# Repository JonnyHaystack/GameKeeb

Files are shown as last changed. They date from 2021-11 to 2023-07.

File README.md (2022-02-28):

# GameKeeb

Keyboard to GameCube adapter powered by Raspberry Pi Pico

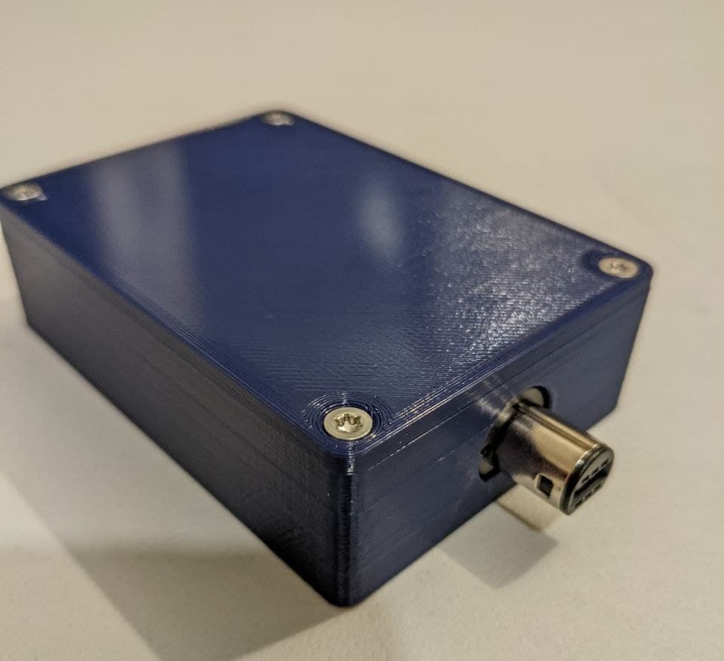
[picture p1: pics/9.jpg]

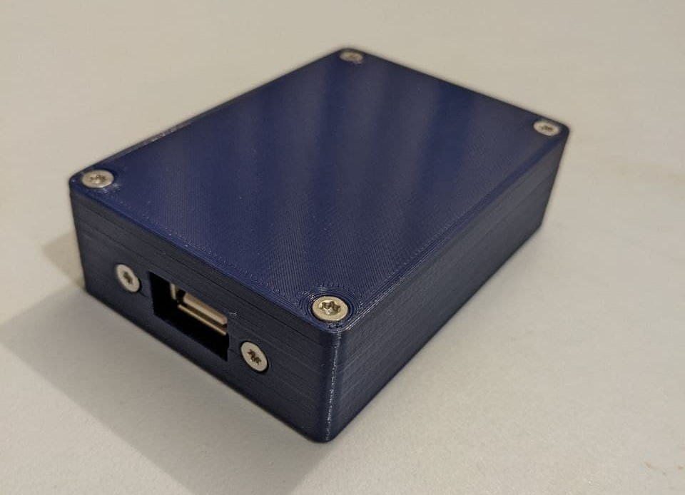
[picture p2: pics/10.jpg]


## Introduction

Someone asked me if I could make them a keyboard to GameCube adapter for
competing in Super Smash Bros Melee. I had the idea to make one using the
Raspberry Pi Pico, because it natively operates at 3.3V supply voltage and logic
level, and it has USB host support built in. Additionally, Arte had already
developed the awesome
[pico-rectangle](https://github.com/JulienBernard3383279/pico-rectangle)
firmware, so I forked it and modified it to read keycodes from a USB keyboard
instead of just GPIO inputs.

Bear in mind that USB host implementation is not as simple as it sounds, and the current
firmware is not guaranteed to work with every keyboard. In particular, it may not support all NKRO (N-Key rollover) keyboards. It should work fine with any keyboard that supports the HID boot protocol, which is very common keyboard and usually recognisable by your keyboard having 6KRO. Many NKRO keyboards will fall back to boot protocol when needed anyway. You can test your key rollover at http://gadzikowski.com/nkeyrollover.html. Support for different keyboards will be further improved in the future.

I do sell these fully assembled, so email me or [join my Discord](https://discord.com/invite/PreBbFgxxY)
if you're interested. As stated above, I cannot guarantee compatibility with
every keyboard, so I accept returns for a full refund (not including
shipping costs).

## Parts used

| Part name | Amount | Link |
|---|---|:---:|
| USB A panel mount | 1 | https://www.ebay.co.uk/itm/231984473033 (alternatively https://www.aliexpress.com/item/32573641881.html) |
| GameCube controller extension cable  | 2 | https://www.ebay.co.uk/itm/193842724956 (alternatively https://www.aliexpress.com/item/4000505687571.html) |
| M3 threaded insert, M3 X D4.0 X L5.2 | 4 | https://www.ebay.co.uk/itm/264096317255 |
| M3x6mm countersunk machine screw | 6 | https://www.ebay.co.uk/itm/222414700032 |
| M2x4mm self-tapping screw | 4 | https://www.ebay.co.uk/itm/383054906364?var=651662203885 |
| Raspberry Pi Pico | 1 | https://shop.pimoroni.com/products/raspberry-pi-pico?variant=32402092294227 |
| Case | 1 | [3D printed](case_files/) |

## Printing the case

The STL files for the case are [included](case_files/) in this repository. I
print them without supports at 0.2mm layer height. It's an easy print and
shouldn't require any special settings.

## Assembly instructions

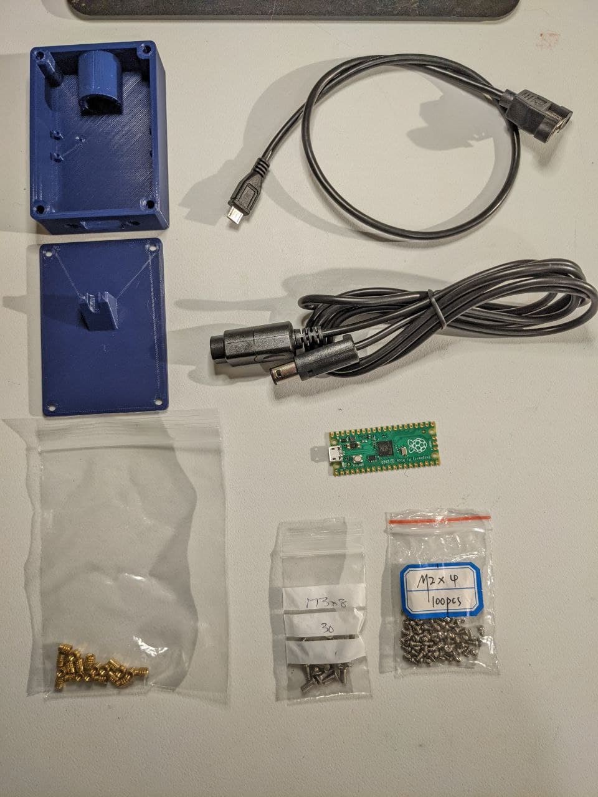
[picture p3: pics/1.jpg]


1. Cut and strip the male end of the GameCube controller extension cable and the
   female end of the USB panel mount. You should strip the outer casing all the
   way up to the connector otherwise it will stick out too much.

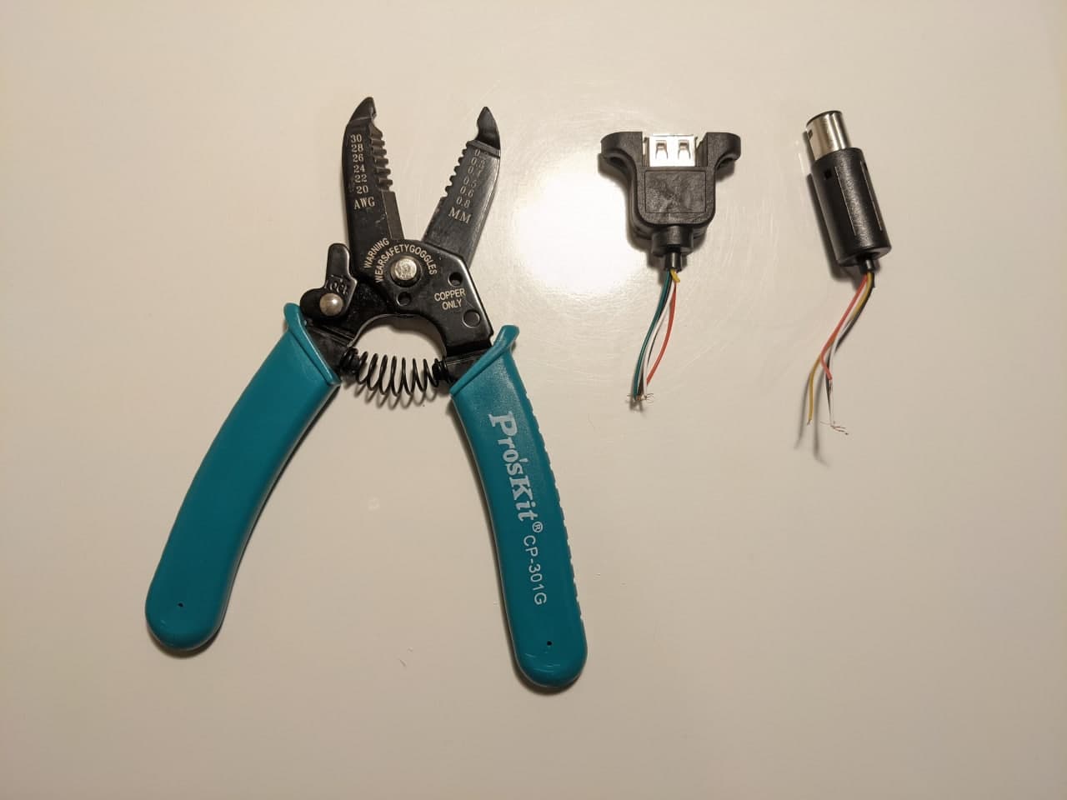
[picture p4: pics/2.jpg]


2. Use a knife to slice/scrape off the two bumps/ridges on the top of the GameCube
   connector. This is necessary for it to fit in the slot in the case. Some cables may not have these, in which case you can ignore this step.

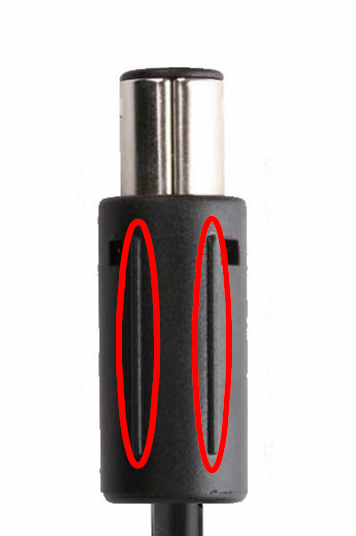
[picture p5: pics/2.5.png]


3. Solder the USB panel mount and the GameCube controller connector to the Pico
   following the wiring diagram below.

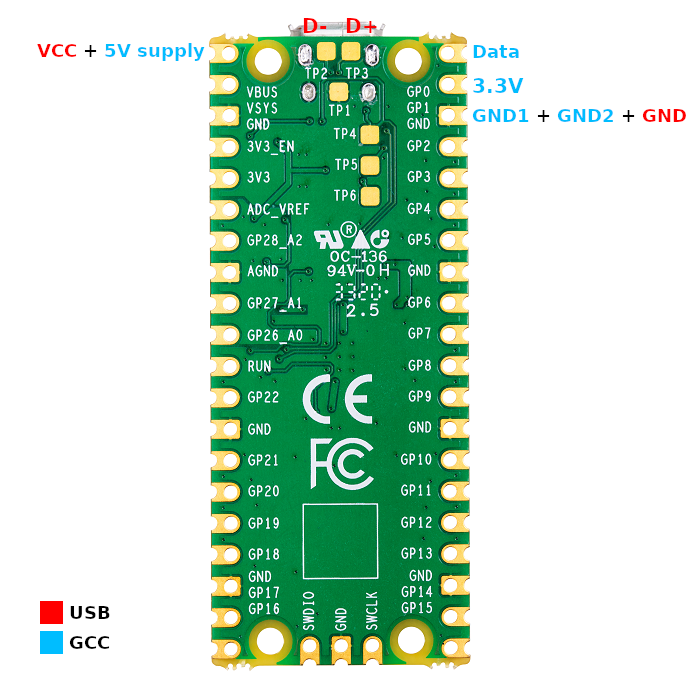
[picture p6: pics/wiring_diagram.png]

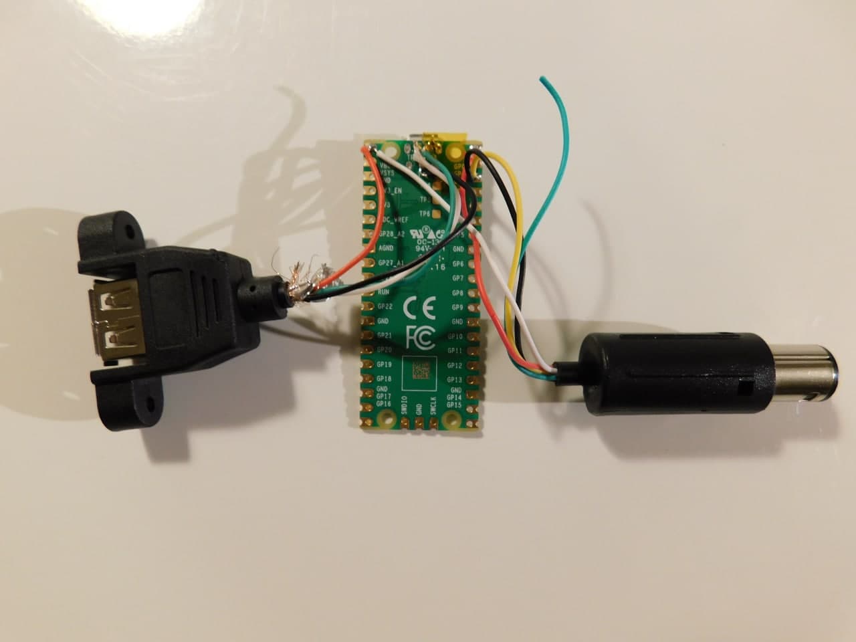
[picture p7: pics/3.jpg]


The USB colour coding is standard and can easily be found online. The GCC colour coding is only standard for official cables
(i.e. cables in actual GameCube controllers). The official colour coding can be
found [here](http://int03.co.uk/crema/hardware/gamecube/gc-control.html).

Based on my testing, the colour coding for the type of extension cable I have
linked is as follows:

- Pin 1 (5V supply): White
- Pin 2 (Data): Red
- Pin 3 (GND1): Black
- Pin 4 (GND2): Yellow
- Pin 6 (3.3V supply): Green

This is not guaranteed to be the same for other cables, and could even vary for
these cables for all I know. You can test it yourself by using a multimeter to
test continuity on the female connector (meaning you would have to strip the
wires on the female connector as well).

Note that these wires are thin enough that you can fit multiple wires into the
pin holes. I take advantage of this to make the wiring simpler. If you have
trouble fitting them you can use any other GND though. There are plenty of them
in convenient locations.

It also is advisable to use kapton tape or some other means of insulation to
prevent any potential shorts between the D+ and D- wires.

4. Prepare the case by inserting threaded inserts. This is done by inserting
   them into the holes and heating them with a soldering iron at around 220C.
   You shouldn't need to push them in. Just let gravity do the work.

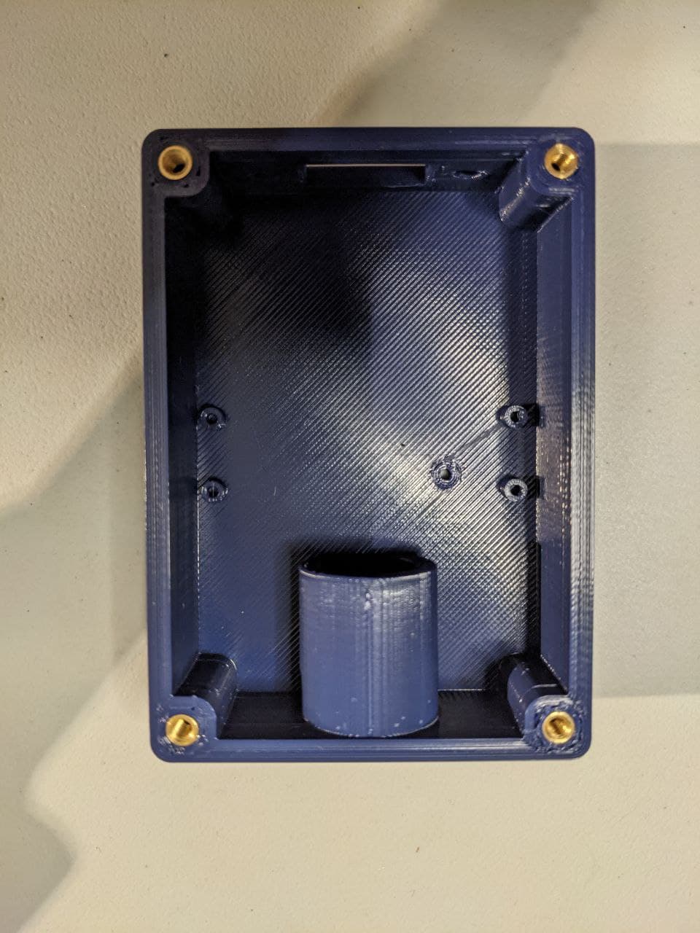
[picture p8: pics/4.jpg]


5. Insert the GameCube connector into the GameCube connector slot.

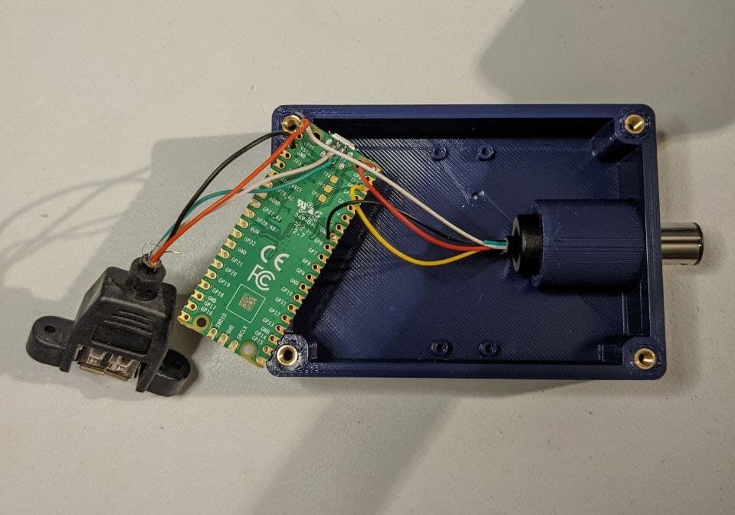
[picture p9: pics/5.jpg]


6. Secure the Pico to the standoffs using the M2x4mm self-tapping screws. Be
   careful not to over-tighten them or break the standoffs.

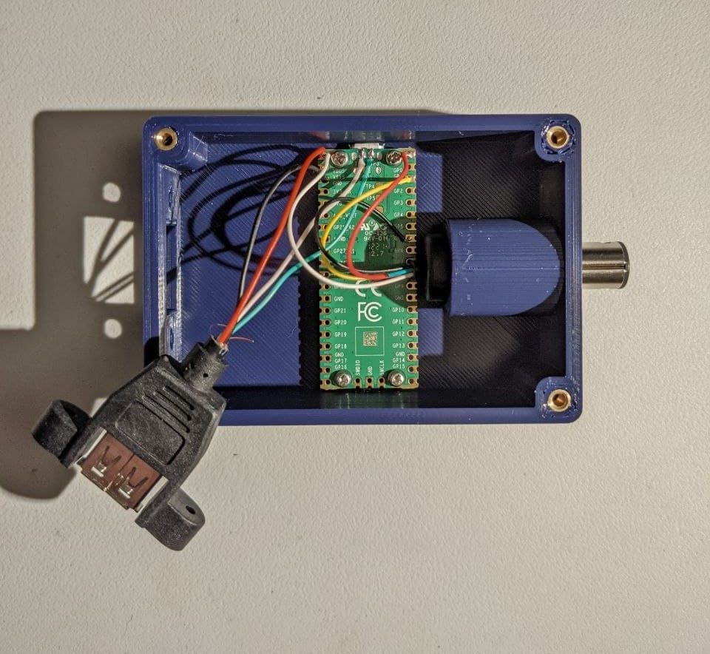
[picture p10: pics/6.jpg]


7. Mount the USB panel mount connector using 2 M3x6mm screws.

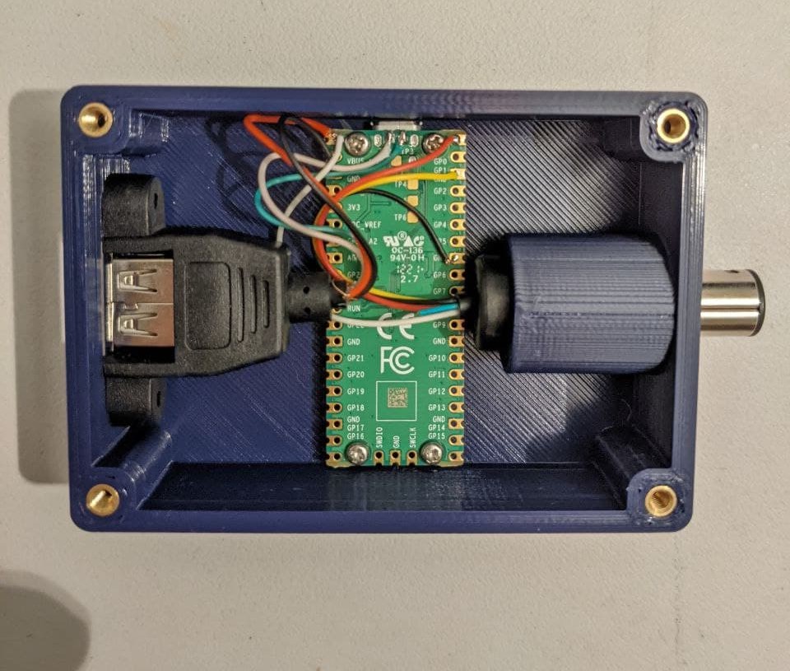
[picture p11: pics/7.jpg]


8. Screw the lid onto the case using 4 M3x6mm screws and making sure that the
   locking piece does not crush any of the wires inside the case.

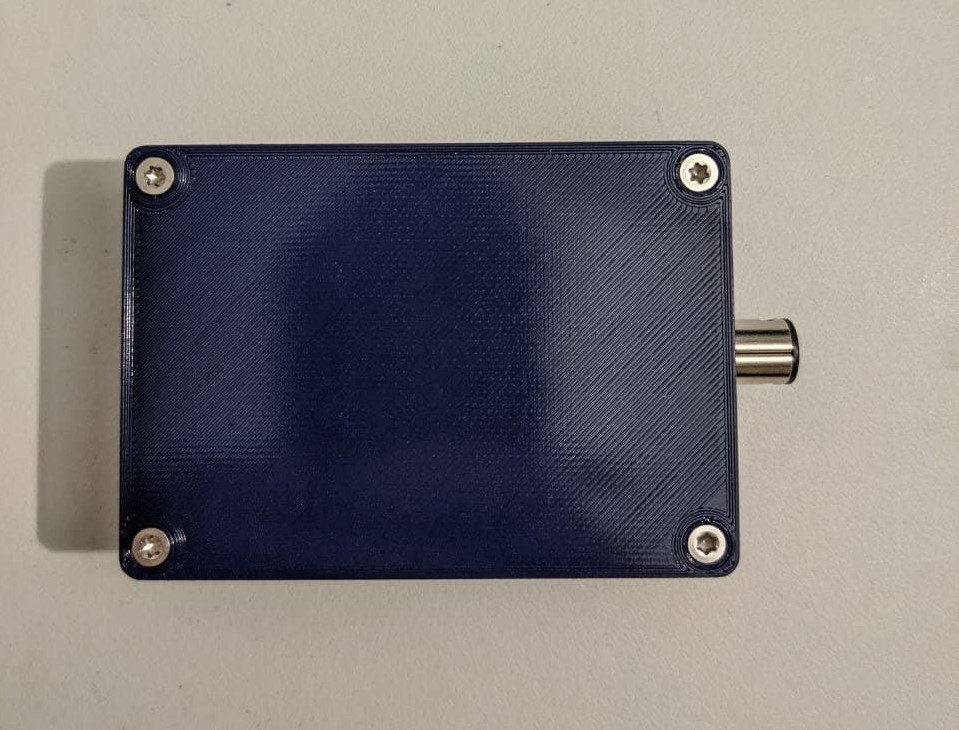
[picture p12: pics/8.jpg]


## Firmware flashing instructions

Now that the assembly is complete, you can flash the firmware. Actually you
should probably have done this beforehand to make sure the microcontroller
works. Anyway...

1. Connect the Pico to your PC via USB while pressing the bootsel button. If you
   have already completed the assembly, you can achieve this by sticking a
   paperclip into the tiny hole in the bottom of the case.

2. The Pico should show up as a flash drive on your PC. Drop the firmware .uf2
   file onto it and it will reprogram itself automatically.

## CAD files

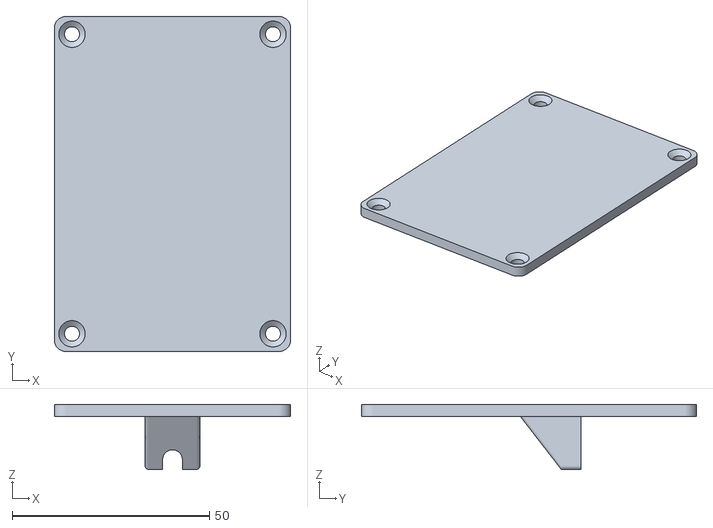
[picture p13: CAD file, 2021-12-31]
case_files/lid.stl
60.0 x 85.0 x 16.5

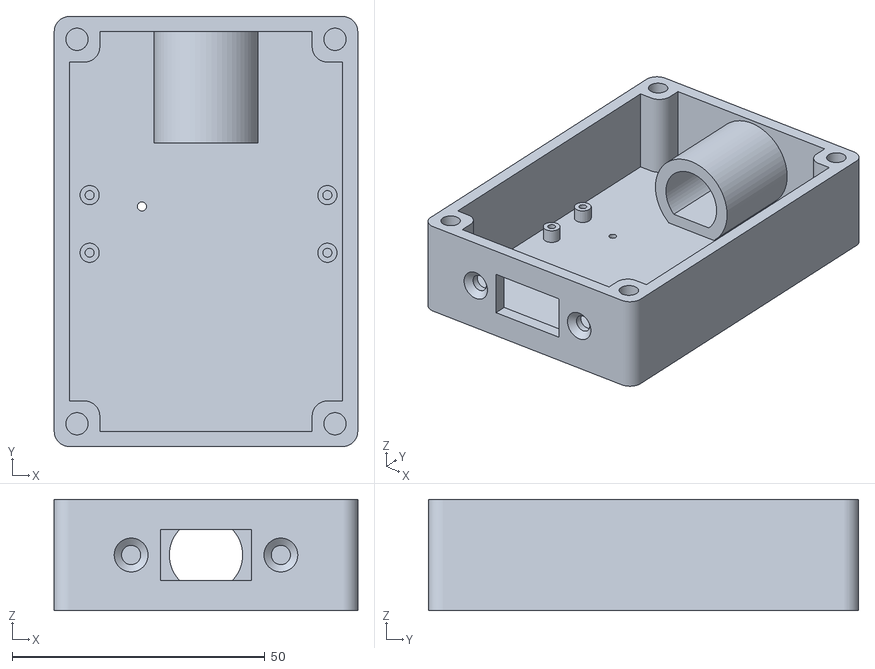
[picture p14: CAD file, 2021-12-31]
case_files/case.stl
60.0 x 85.0 x 22.0

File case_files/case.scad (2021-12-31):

include <BOSL/constants.scad>
include <NopSCADlib/lib.scad>
use <BOSL/metric_screws.scad>
use <BOSL/shapes.scad>
use <BOSL/transforms.scad>

// Epsilon value for offsetting coincident face differences.
E = 0.004;

case_width = 60;
case_length = 85;
case_height = 22;

wall_thickness = 3;
corner_radius = 3;
corner_extension_thickness = wall_thickness * 2;

lid_thickness = 3;
lid_screw_hole_diameter = 3.8;

threaded_insert_hole_diameter = 4.4;
threaded_insert_hole_depth = 7;

usb_screw_hole_diameter = 3.8;

usb_port_hole_height = 10;
usb_port_hole_width = 18;
usb_port_screw_to_midpoint = 14.8;

gcc_connector_diameter = 14;
gcc_connector_length = 28.8;
gcc_connector_centre_to_flat_side = 5;
gcc_connector_slot_clearance = 0.25;
gcc_connector_slot_thickness = 3;
gcc_connector_slot_length = 25;

gcc_connector_stopper_thickness = 5;
gcc_connector_stopper_reinforcement_angle = 55;
gcc_connector_stopper_gap_size = 5;
gcc_connector_stopper_corner_radius = 1;

pico_width = 21;
pico_height = 51;
pico_centre_x = 0.5;
pico_centre_y = wall_thickness / 2;
pico_screw_hole_centre_x_offset = 2;
pico_screw_hole_centre_y_offset = 4.8;
pico_screw_hole_x = (
  pico_centre_x
  + (pico_height / 2)
  - pico_screw_hole_centre_x_offset
);
pico_screw_hole_y = (
  pico_centre_y
  + (pico_width / 2)
  - pico_screw_hole_centre_y_offset
);

pico_mounting_hole_depth = 3;
pico_mounting_hole_diameter = 1.8;
pico_mounting_hole_wall_thickness = 1;

reset_hole_x_offset = 12.33;
reset_hole_y_offset = 7.05;
reset_hole_x = (
  -pico_centre_x
  + (pico_height / 2)
  - reset_hole_x_offset
);
reset_hole_y = (
  pico_centre_y
  + (pico_width / 2)
  - reset_hole_y_offset
);
reset_hole_diameter = 1.6;

/* Begin modules */ 
case();
lid();
pico_preview();


module case() {
  difference() {
    case_with_corner_extensions();

    // Move to the near end of the case and cut out USB panel mount holes.
    translate([0, -case_length / 2 - E, 0]) {
      usb_panel_mount();
    }

    // Move to the far end of the case and cut out GCC connector hole.
    translate([0, case_length / 2 + E, 0]) {
      gcc_connector_hole();
    }

    // Cut holes for threaded inserts in the centre of the squares created by
    // the outer and inner corner pieces.
    threaded_insert_holes();

    // Cut out reset button hole for Pico.
    pico_reset_hole();
  }

  // Move to the far end of the case and create GCC connector slot.
  translate([0, case_length / 2 + E, 0]) {
    gcc_connector_slot();
  }

  // Create standoffs for the Raspberry Pi Pico.
  pico_standoffs();
}

module case_with_corner_extensions() {
  difference() {
    // Base shape.
    cuboid([
      case_width,
      case_length,
      case_height
    ], fillet=corner_radius, edges=EDGES_Z_ALL);

    // Hollow out the cuboid.
    translate([0, 0, wall_thickness])
      cuboid([
        case_width - wall_thickness * 2,
        case_length - wall_thickness * 2,
        case_height
      ]);
  }

  // Extend corners inwards.
  corner_extensions();
}

module usb_panel_mount() {
  // USB port hole.
  cuboid([
    usb_port_hole_width,
    wall_thickness * 2 + 1,
    usb_port_hole_height
  ]);

  // USB port screw holes.
  xflip_copy() translate([usb_port_screw_to_midpoint, 0, 0]) {
    metric_bolt(
      size=lid_screw_hole_diameter,
      l=wall_thickness + E * 2,
      headtype="countersunk",
      pitch=0,
      orient=ORIENT_YNEG,
      align=V_BACK
    );
  }
}

module gcc_connector_hole() {
  // Create hole in wall for GCC connector.
  difference() {
    ycyl(
      l=wall_thickness + E * 2,
      d=gcc_connector_diameter + gcc_connector_slot_clearance * 2,
      align=V_FWD
    );

    translate([
      0,
      0,
      -(gcc_connector_centre_to_flat_side + gcc_connector_slot_clearance)
    ])
      cuboid([
        gcc_connector_diameter,
        wall_thickness + E * 2,
        gcc_connector_slot_thickness
      ], align=V_DOWN + V_FWD);
  }
}

module gcc_connector_slot() {
  // We again create the interior slot shape but this time in 2D. We then create
  // a shell around this 2D slot shape, and linear extrude it for the length of
  // the slot to create the final 3D exterior slot shape.
  rotate([90])
    linear_extrude(gcc_connector_slot_length) 
      shell2d(gcc_connector_slot_thickness)
        // This circle and square are equivalent to the ycyl and cuboid in
        // gcc_connector_hole().
        difference() {
          circle(d=gcc_connector_diameter + gcc_connector_slot_clearance * 2);
          translate([
            0,
            -(gcc_connector_centre_to_flat_side
              + gcc_connector_slot_clearance
              + gcc_connector_slot_thickness / 2)
          ])
            square([
              gcc_connector_diameter,
              gcc_connector_slot_thickness
            ], center=true);
          }
}

module corner_extensions() {
  // Inner corner blocks for threaded inserts to go into.
  yflip_copy() xflip_copy() translate([
    case_width / 2 - wall_thickness,
    case_length / 2 - wall_thickness,
    case_height / 2
  ])
    // Corner extension thing.
    cuboid(
      [
        corner_extension_thickness,
        corner_extension_thickness,
        case_height - wall_thickness
      ],
      fillet=corner_radius,
      edges=EDGE_FR_LF,
      align=V_DOWN + V_FWD + V_LEFT
    );
}

module threaded_insert_holes() {
  // Place hole for threaded insert at centre point of extended inner corners.
  yflip_copy() xflip_copy() translate([
    (case_width - wall_thickness - corner_extension_thickness) / 2,
    (case_length - wall_thickness - corner_extension_thickness) / 2,
    case_height / 2 + E
  ])
    zcyl(
      d=threaded_insert_hole_diameter,
      l=threaded_insert_hole_depth + E,
      align=V_DOWN
    );
}

module pico_standoffs() {
  yflip_copy(cp=[0, pico_centre_y]) xflip_copy(cp=[pico_centre_x, 0])
    translate([
      pico_screw_hole_x,
      pico_screw_hole_y,
      -case_height / 2 + wall_thickness
    ])
      linear_extrude(pico_mounting_hole_depth)
        shell2d(pico_mounting_hole_wall_thickness)
          circle(d=pico_mounting_hole_diameter);
}

module pico_reset_hole() {
  translate([
    -reset_hole_x,
    reset_hole_y,
    -case_height / 2 + wall_thickness + E
  ])
    zcyl(d=pico_mounting_hole_diameter, l=wall_thickness + E * 2, align=V_DOWN);
}

module lid() {
  lid_z_offset = case_height / 2;

  translate([0, 0, lid_z_offset]) {
    difference() {
      cuboid(
        [case_width, case_length, lid_thickness],
        fillet=corner_radius,
        edges=EDGES_Z_ALL,
        align=V_UP
      );

      // Cut out screw holes in the lid.
      lid_screw_holes();
    }

    // Slot thing that holds GCC connector in place.
    gcc_connector_stopper();
  }
}

module lid_screw_holes() {
  // Place lid screw hole in same place as threaded insert hole.
  yflip_copy() xflip_copy() translate([
    (case_width - wall_thickness - corner_extension_thickness) / 2,
    (case_length - wall_thickness - corner_extension_thickness) / 2,
    lid_thickness + E
  ])
    metric_bolt(
      size=lid_screw_hole_diameter,
      l=6,
      headtype="countersunk",
      pitch=0,
      align=V_DOWN
    );
}

module gcc_connector_stopper() {
  gcc_connector_stopper_height = (
    case_height
    - wall_thickness
    - pico_mounting_hole_depth
    - 2.5
  );

  gcc_connector_stopper_reinforcement_length = (
    pow(tan(gcc_connector_stopper_reinforcement_angle), -1)
    * gcc_connector_stopper_height
  );
  
  // Move to position for stopper.
  translate([
    0,
    (
      case_length / 2
      - gcc_connector_length - 0.5
      - gcc_connector_stopper_thickness / 2
    ),
    0
  ])
    difference() {
      // The stopper itself.
      hull() {
        cuboid([
          gcc_connector_diameter,
          gcc_connector_stopper_thickness,
          gcc_connector_stopper_height
        ], align=V_DOWN, fillet=1, edges=EDGES_Y_BOT);

        xflip_copy() translate([
          -(gcc_connector_diameter / 2 - gcc_connector_stopper_corner_radius),
          -(
            gcc_connector_stopper_thickness / 2
            + gcc_connector_stopper_reinforcement_length
          ),
          0
        ])
          cylinder(r=gcc_connector_stopper_corner_radius, h=E);
    }

    // Slot/gap for cable/wires coming out of GCC connector.
    hull() {
      translate([0, 0, -case_height / 2])
        ycyl(
          d=gcc_connector_stopper_gap_size,
          l=(
            gcc_connector_stopper_thickness
            + gcc_connector_stopper_reinforcement_length
            + E
          )
        );
      translate([0, 0, -gcc_connector_stopper_height])
        cuboid([
          gcc_connector_stopper_gap_size,
          (
            gcc_connector_stopper_thickness
            + gcc_connector_stopper_reinforcement_length
            + E
          ),
          E
        ], align=V_UP);
    }
  }
}
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

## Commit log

2021-11-29 Add first revision of GCC connector stopper in lid
    [case.scad, case.stl, lid.stl]
2021-11-29 Fix formatting
    [case.scad]
2021-11-30 Make USB panel mount screws countersunk and decrease wall thickness to 3mm
    [case.scad]
2021-11-30 Reinforce GCC connector stopper
    [case.scad, case.stl, lid.stl]
2023-07-29 Update wiring diagram
